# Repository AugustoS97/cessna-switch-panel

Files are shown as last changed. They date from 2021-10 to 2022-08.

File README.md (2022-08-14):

# cessna-switch-panel

## Descripción

Panel para interruptores de luces y magnetos para Cessna 172 y otros simuladores de vuelo. Diseñado para ser compatible con MobiFlight y FSX, MSFS2020, Xplane y Prepar3D.

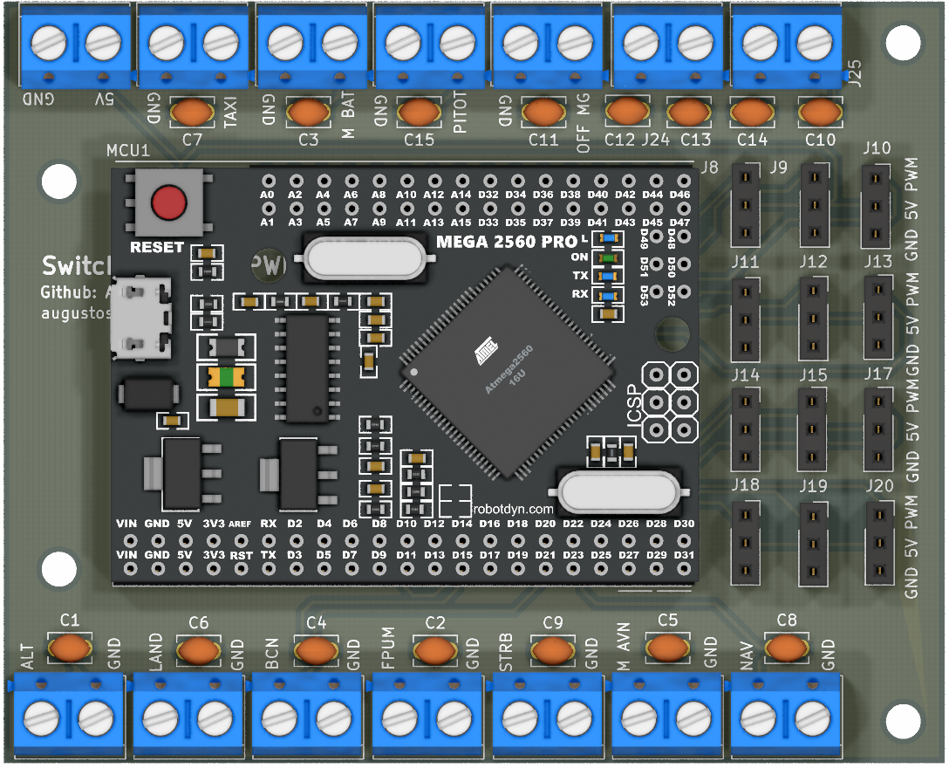
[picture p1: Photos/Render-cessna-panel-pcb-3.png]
PCB Top


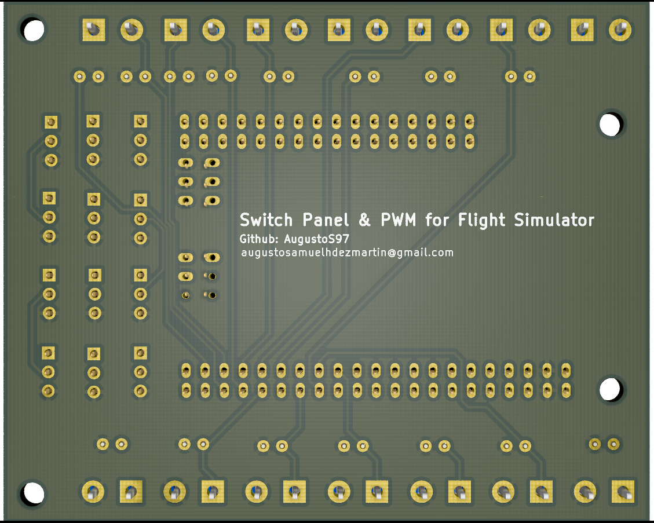
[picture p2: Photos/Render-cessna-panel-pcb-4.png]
PCB Bottom


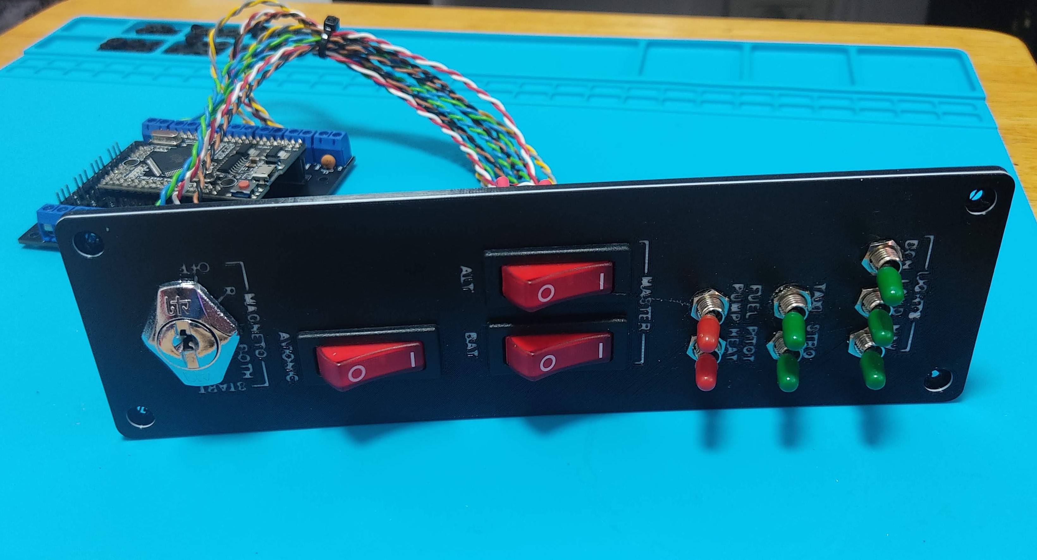
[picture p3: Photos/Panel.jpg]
Panel


## Contenido del proyecto

- En la carpeta cessna-panel-pcb se incluye el diseño de PCB para ser controlado con un arduino Mega 2560 Pro, con los ficheros GERBER para ser pedido en JLCPCB.
- En la carpeta Frame-design se localizan los diseños 3D de los marcos para los interruptores tanto para instalación vertical como horizontal.
- En la carpeta PCB-Support se localizan los diseños 3D de la carcasa para la electrónica.
- En la carpeta Mobiflight Confif se localiza el fichero de configuración d eMobiflight para Cessna 172 y MSFS2020.

Enlace del diseño de [paneles](https://www.thingiverse.com/thing:5461243) y [carcasa](https://www.thingiverse.com/thing:5461228) en Thingiverse.

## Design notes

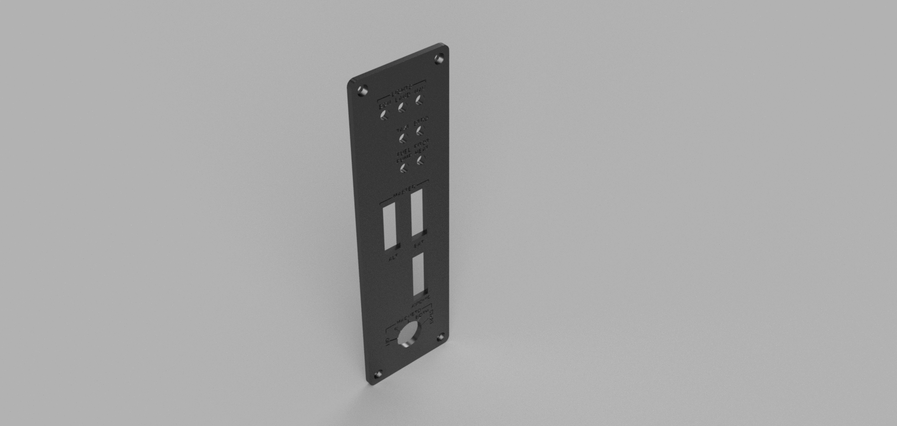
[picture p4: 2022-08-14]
Frame-design/Vertical version/IMAGES/Frame-design-switches-vertical.png

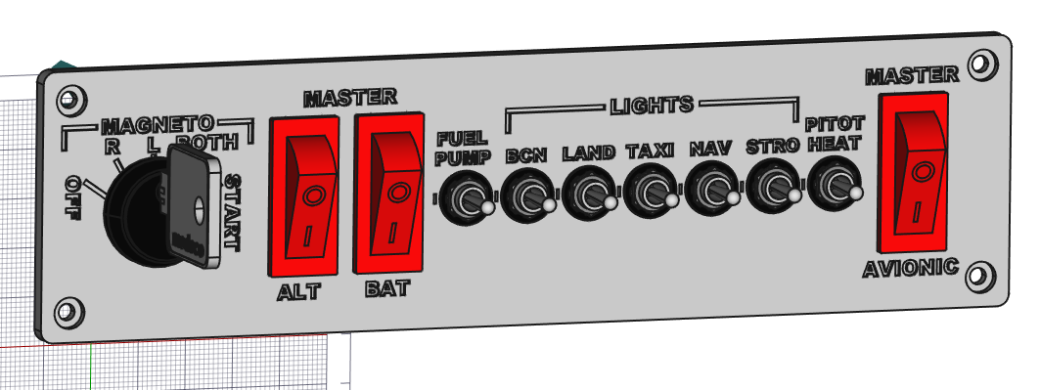
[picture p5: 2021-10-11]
Frame-design/Horizontal version/IMAGES/Frame-design-switches-vertical_2.png

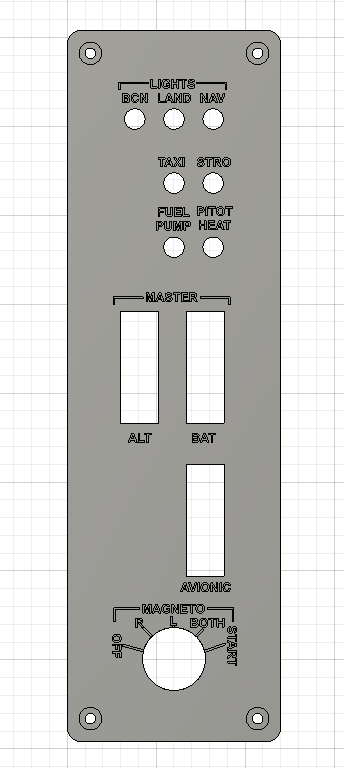
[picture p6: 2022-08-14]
Frame-design/Vertical version/IMAGES/Frame-design-switches-vertical_2.png

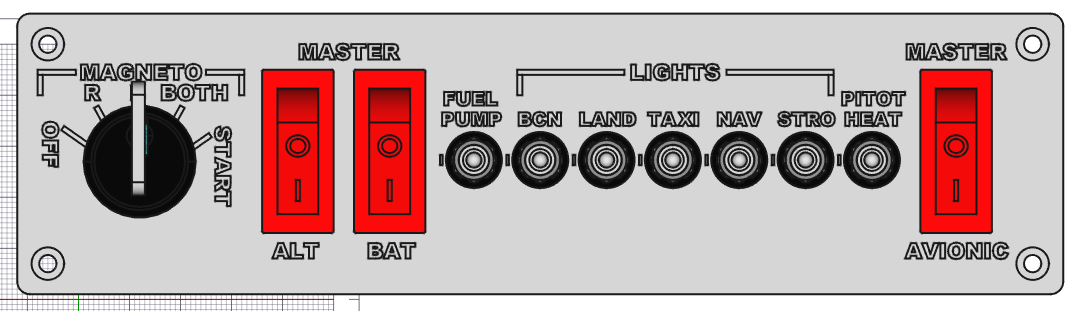
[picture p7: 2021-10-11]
Frame-design/Horizontal version/IMAGES/Frame-design-switches-vertical_0.png

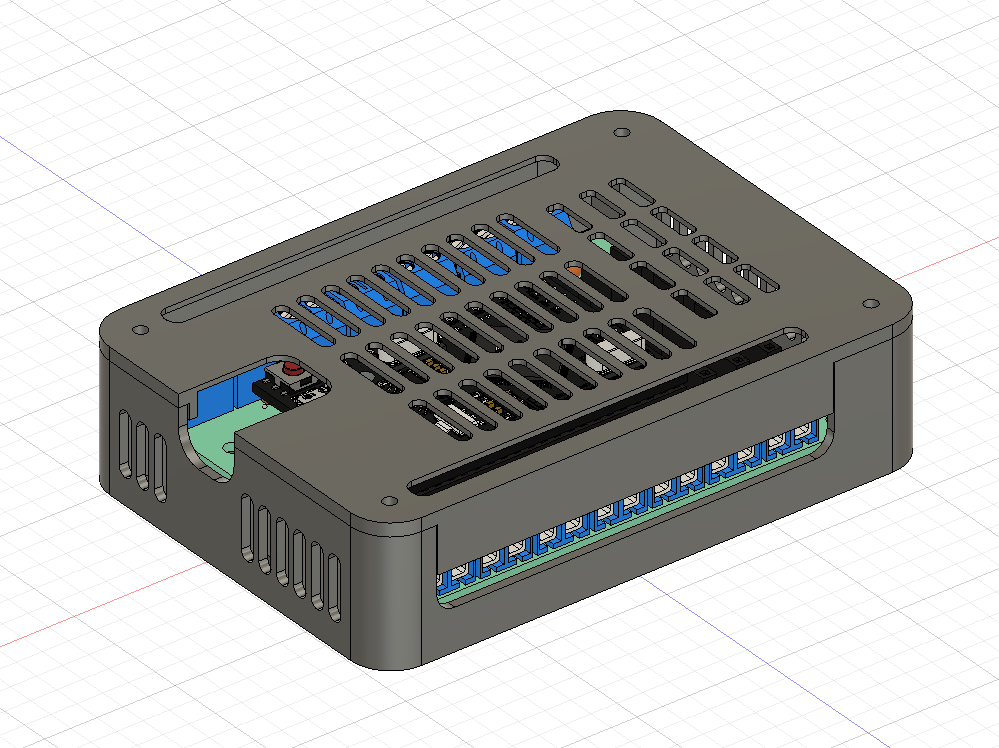
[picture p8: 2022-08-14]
PCB-Support/IMAGES/Diseño de soporte.png

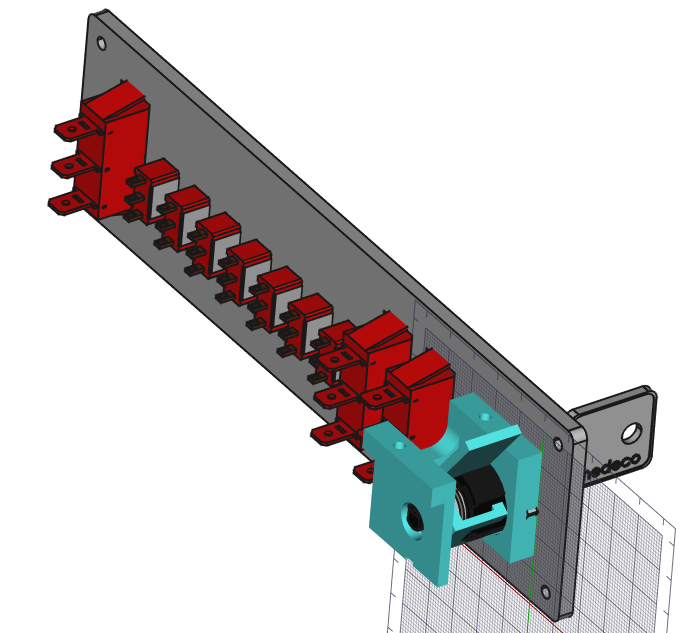
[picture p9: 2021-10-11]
Frame-design/Horizontal version/IMAGES/Frame-design-switches-vertical_1.png

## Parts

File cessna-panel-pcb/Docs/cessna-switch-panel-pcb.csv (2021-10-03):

Ref | Qnty | Value | Cmp name | Footprint | Description | Vendor
C1, C2, C3, C4, C5, C6, C7, C8, C9, C10, C11, C12, C13, C14, C15, | 15 | 10nF | C_Small | Capacitor_THT:C_Disc_D3.8mm_W2.6mm_P2.50mm | Unpolarized capacitor, small symbol
J1, J2, J3, J4, J5, J6, J7, J16, J21, J22, J23, J24, J25, J26, | 14 | Screw_Terminal_01x02 | Screw_Terminal_01x02 | TerminalBlock:TerminalBlock_bornier-2_P5.08mm | Generic screw terminal, single row, 01x02, script generated (kicad-library-utils/schlib/autogen/connector/)
J8, | 1 | PWM1_CONN | Conn_01x03 | Connector_PinSocket_2.54mm:PinSocket_1x03_P2.54mm_Vertical | Generic connector, single row, 01x03, script generated (kicad-library-utils/schlib/autogen/connector/)
J9, | 1 | PWM2_CONN | Conn_01x03 | Connector_PinSocket_2.54mm:PinSocket_1x03_P2.54mm_Vertical | Generic connector, single row, 01x03, script generated (kicad-library-utils/schlib/autogen/connector/)
J10, | 1 | PWM3_CONN | Conn_01x03 | Connector_PinSocket_2.54mm:PinSocket_1x03_P2.54mm_Vertical | Generic connector, single row, 01x03, script generated (kicad-library-utils/schlib/autogen/connector/)
J11, | 1 | PWM4_CONN | Conn_01x03 | Connector_PinSocket_2.54mm:PinSocket_1x03_P2.54mm_Vertical | Generic connector, single row, 01x03, script generated (kicad-library-utils/schlib/autogen/connector/)
J12, | 1 | PWM5_CONN | Conn_01x03 | Connector_PinSocket_2.54mm:PinSocket_1x03_P2.54mm_Vertical | Generic connector, single row, 01x03, script generated (kicad-library-utils/schlib/autogen/connector/)
J13, | 1 | PWM6_CONN | Conn_01x03 | Connector_PinSocket_2.54mm:PinSocket_1x03_P2.54mm_Vertical | Generic connector, single row, 01x03, script generated (kicad-library-utils/schlib/autogen/connector/)
J14, | 1 | PWM7_CONN | Conn_01x03 | Connector_PinSocket_2.54mm:PinSocket_1x03_P2.54mm_Vertical | Generic connector, single row, 01x03, script generated (kicad-library-utils/schlib/autogen/connector/)
J15, | 1 | PWM8_CONN | Conn_01x03 | Connector_PinSocket_2.54mm:PinSocket_1x03_P2.54mm_Vertical | Generic connector, single row, 01x03, script generated (kicad-library-utils/schlib/autogen/connector/)
J17, | 1 | PWM9_CONN | Conn_01x03 | Connector_PinSocket_2.54mm:PinSocket_1x03_P2.54mm_Vertical | Generic connector, single row, 01x03, script generated (kicad-library-utils/schlib/autogen/connector/)
J18, | 1 | PWM10_CONN | Conn_01x03 | Connector_PinSocket_2.54mm:PinSocket_1x03_P2.54mm_Vertical | Generic connector, single row, 01x03, script generated (kicad-library-utils/schlib/autogen/connector/)
J19, | 1 | PWM11_CONN | Conn_01x03 | Connector_PinSocket_2.54mm:PinSocket_1x03_P2.54mm_Vertical | Generic connector, single row, 01x03, script generated (kicad-library-utils/schlib/autogen/connector/)
J20, | 1 | PWM12_CONN | Conn_01x03 | Connector_PinSocket_2.54mm:PinSocket_1x03_P2.54mm_Vertical | Generic connector, single row, 01x03, script generated (kicad-library-utils/schlib/autogen/connector/)
MCU1, | 1 | Master_Arduino_Mega_Embebido_Arduino_Mega_v3 | Master_Arduino_Mega_Embebido_Arduino_Mega_v3 | Mega2560-pro-mini-radio:MEGA_Embebido

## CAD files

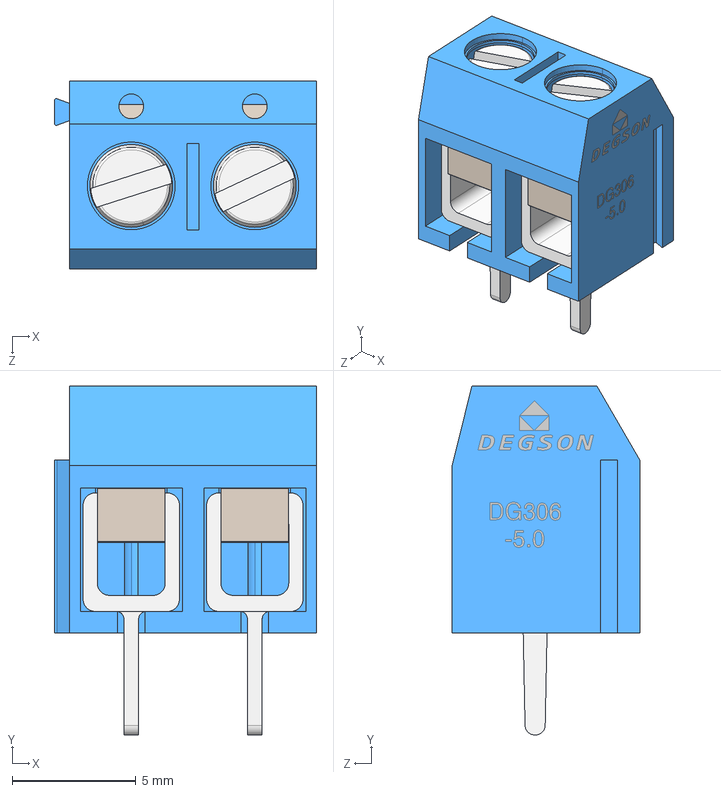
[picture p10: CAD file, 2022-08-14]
cessna-panel-pcb/3D Model/DG306-5.STEP
10.6 x 14.1 x 7.60 mm
Case
Screw x 2
Terminal x 2
Spring x 2

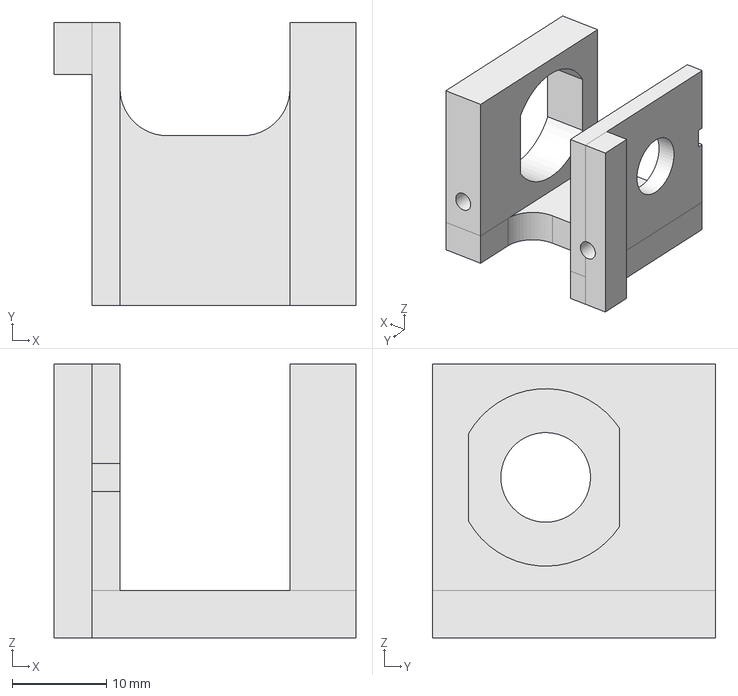
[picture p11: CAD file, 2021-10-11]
Frame-design/Horizontal version/AXUILIAR DESIGN/key-switch/key_switch.FCStd
32.0 x 30.0 x 29.0 mm

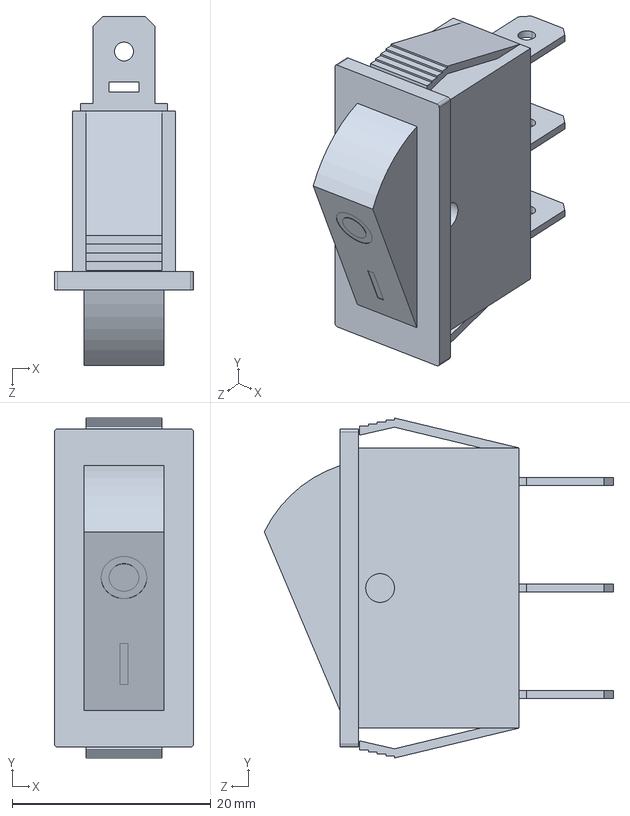
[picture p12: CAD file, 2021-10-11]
Frame-design/Horizontal version/AXUILIAR DESIGN/Single Pole Rocker Switch.STEP
14.0 x 34.2 x 35.1 mm

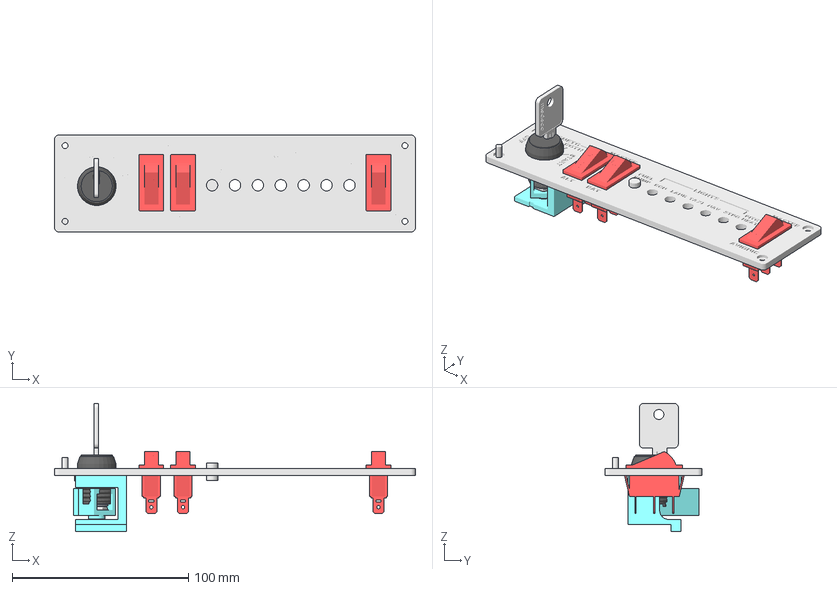
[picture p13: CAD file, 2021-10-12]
Frame-design/Horizontal version/Frame.FCStd
205.0 x 55.0 x 72.9 mm
Cilindro
Cilindro001
Panel_grabado_switches_bordes_red
Outer-Medeco-Lock
Inner-Medeco-Lock
Washer-4-Lock-Latch
Nut-4-Lock-Latch
Nut-4-Medeco-Lock
Key-4-Medeco-Lock
Single Pole Rocker Switch002
Single Pole Rocker Switch001
Single Pole Rocker Switch
key_switch
Redesigned_Spring_Back_Handle

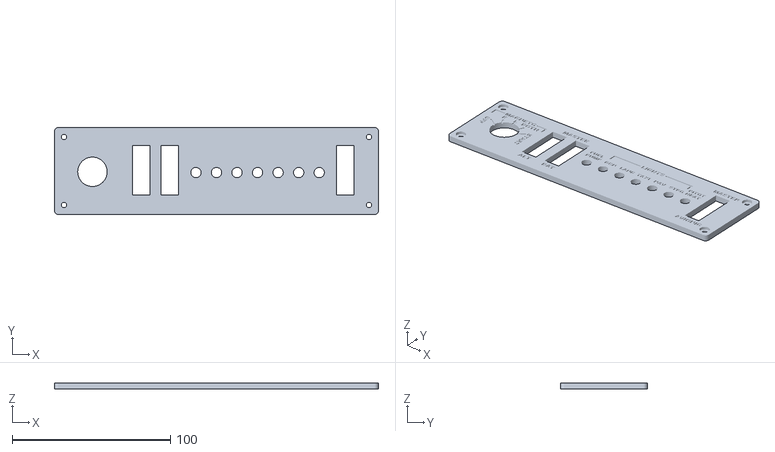
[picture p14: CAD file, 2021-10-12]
Frame-design/Horizontal version/STL/Frame-design-switches-horizontal.stl
205.0 x 55.0 x 4.00

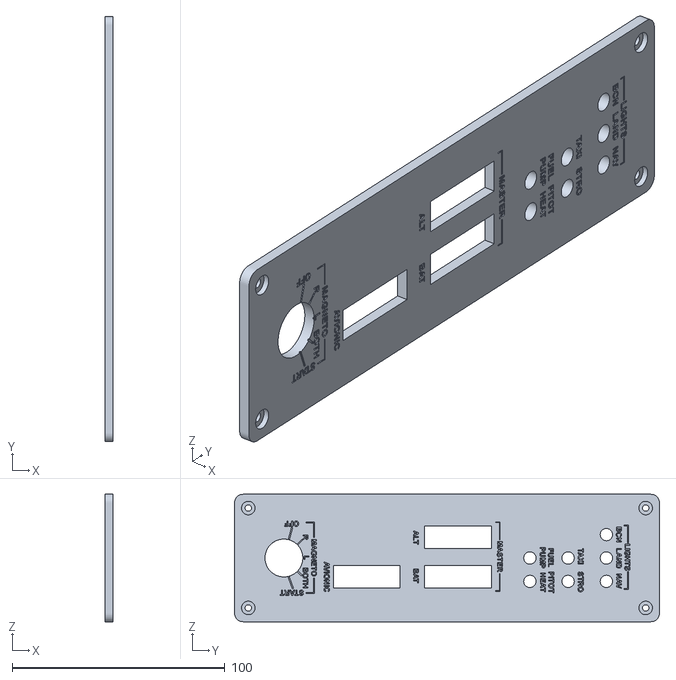
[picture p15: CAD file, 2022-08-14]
Frame-design/Vertical version/STL/Frame-design-switches-vertical.stl
3.60 x 200.0 x 60.0

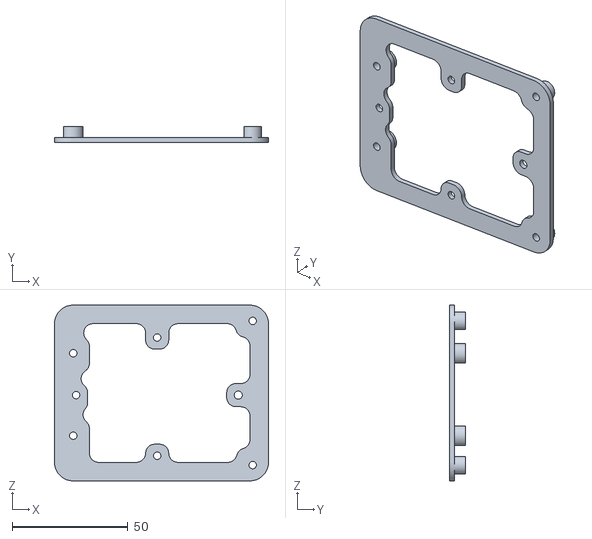
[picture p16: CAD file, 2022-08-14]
PCB-Support/STL/Soprte-PCB-Switch.stl
92.4 x 6.80 x 75.9

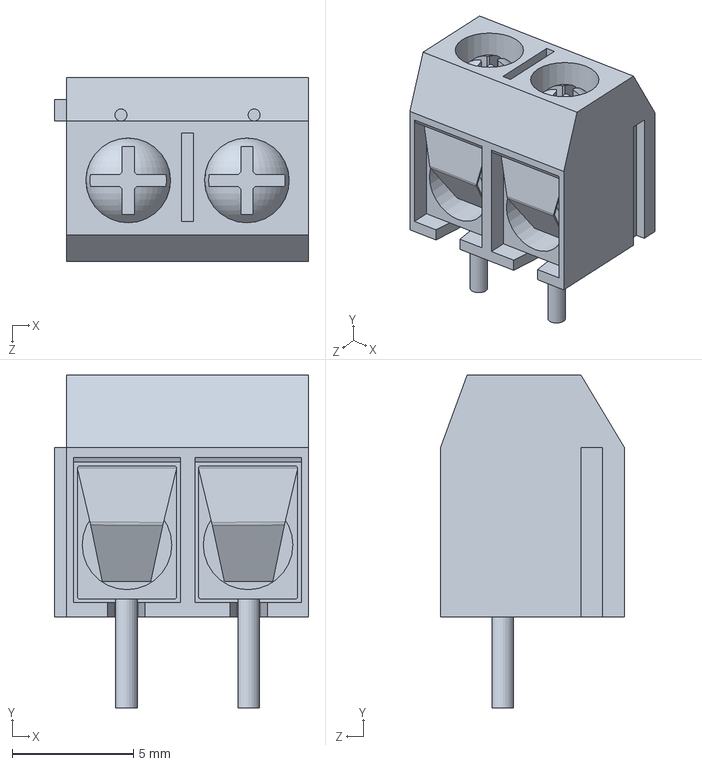
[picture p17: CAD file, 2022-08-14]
cessna-panel-pcb/3D Model/bornera.SLDPRT
10.5 x 13.8 x 7.60 mm

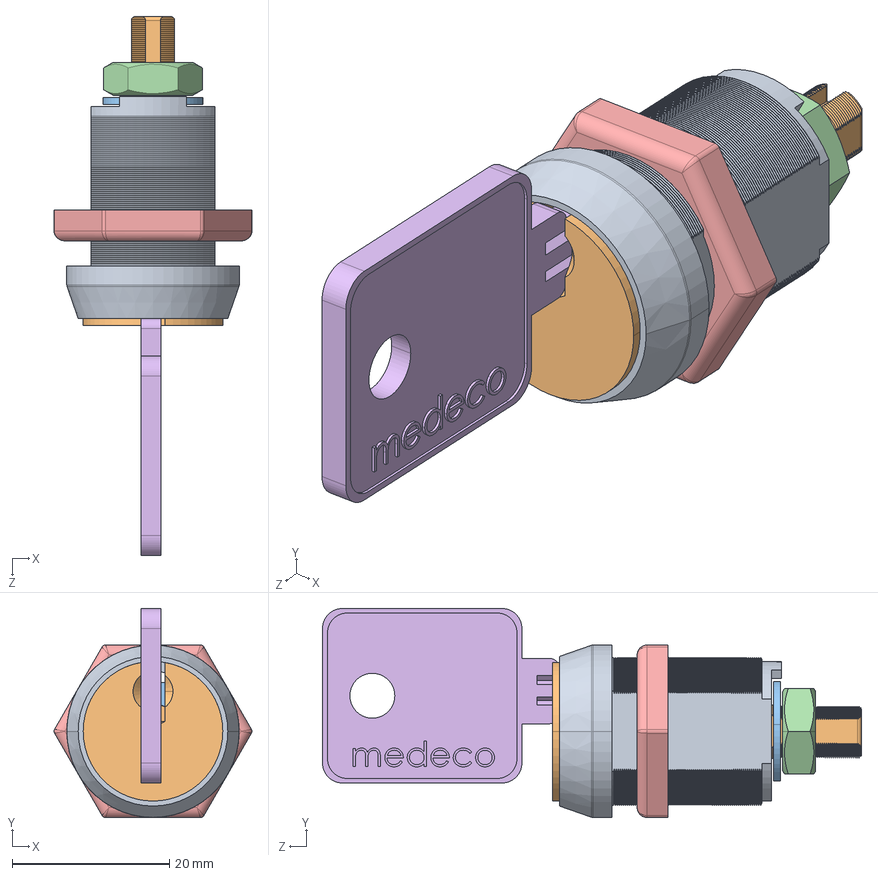
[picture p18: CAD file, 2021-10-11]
Frame-design/Horizontal version/AXUILIAR DESIGN/key-switch/STEP LOCK_and_KEY.STEP
25.2 x 26.6 x 68.6 mm
Outer-Medeco-Lock
Inner-Medeco-Lock
Washer-4-Lock-Latch
Nut-4-Lock-Latch
Nut-4-Medeco-Lock
Key-4-Medeco-Lock

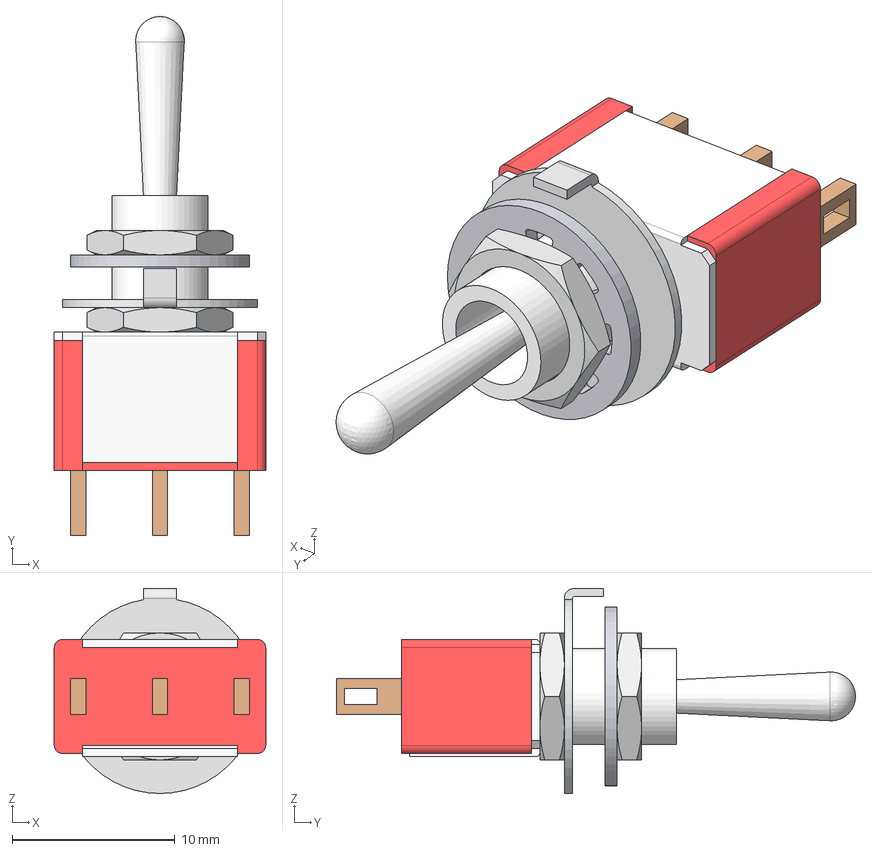
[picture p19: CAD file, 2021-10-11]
Frame-design/Horizontal version/AXUILIAR DESIGN/SPDT Toggle Switch.stp
13.0 x 31.9 x 12.6 mm
SPDT Toggle Switch Base
SPDT Toggle Switch Pin x 3
SPDT Toggle Switch Treaded Tube
Toggle Switch
M6x0.5 Hex Nut x 2
SPDT Toggle Switch Anti-Rotation Washer
AS 1969 (Internal Tooth Lock Washer Type A) M6

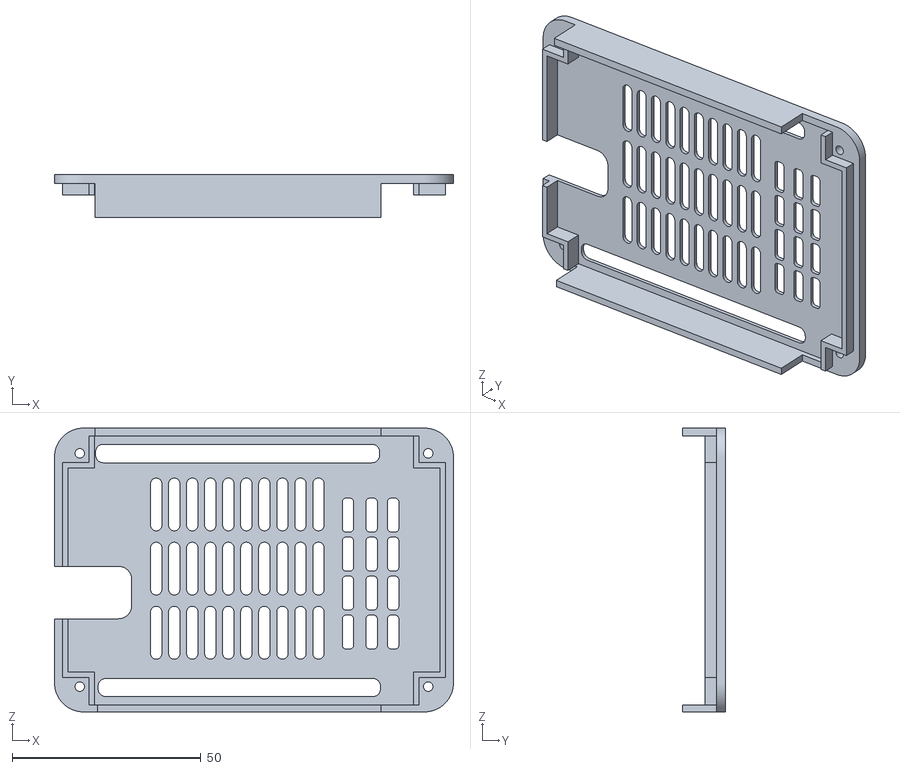
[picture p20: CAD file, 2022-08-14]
PCB-Support/STL/Caja-PCB-Switch-Tapa.stl
105.8 x 11.5 x 75.2

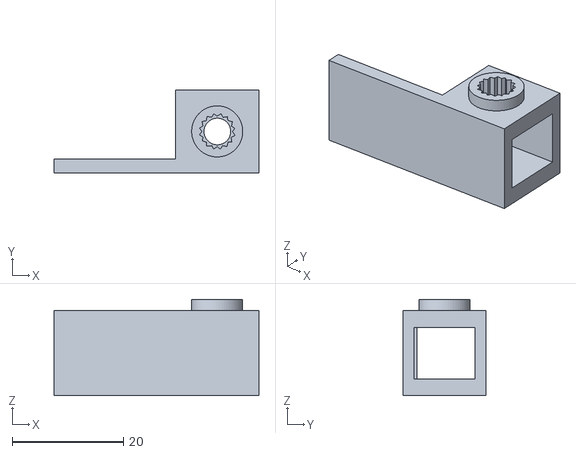
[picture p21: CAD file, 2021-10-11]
Frame-design/Horizontal version/AXUILIAR DESIGN/key-switch/Redesigned_Spring_Back_Handle.stl
36.9 x 15.0 x 17.3

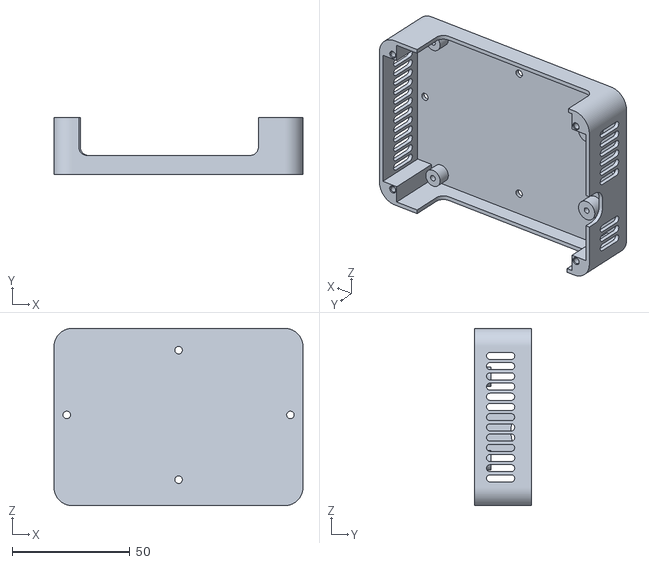
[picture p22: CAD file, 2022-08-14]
PCB-Support/STL/Caja-PCB-Switch-Inf.stl
105.8 x 24.0 x 75.2

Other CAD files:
Frame-design/Horizontal version/AXUILIAR DESIGN/key-switch/key_switch.stl
Frame-design/Vertical version/Fusion 360/Estructura v25.f3d

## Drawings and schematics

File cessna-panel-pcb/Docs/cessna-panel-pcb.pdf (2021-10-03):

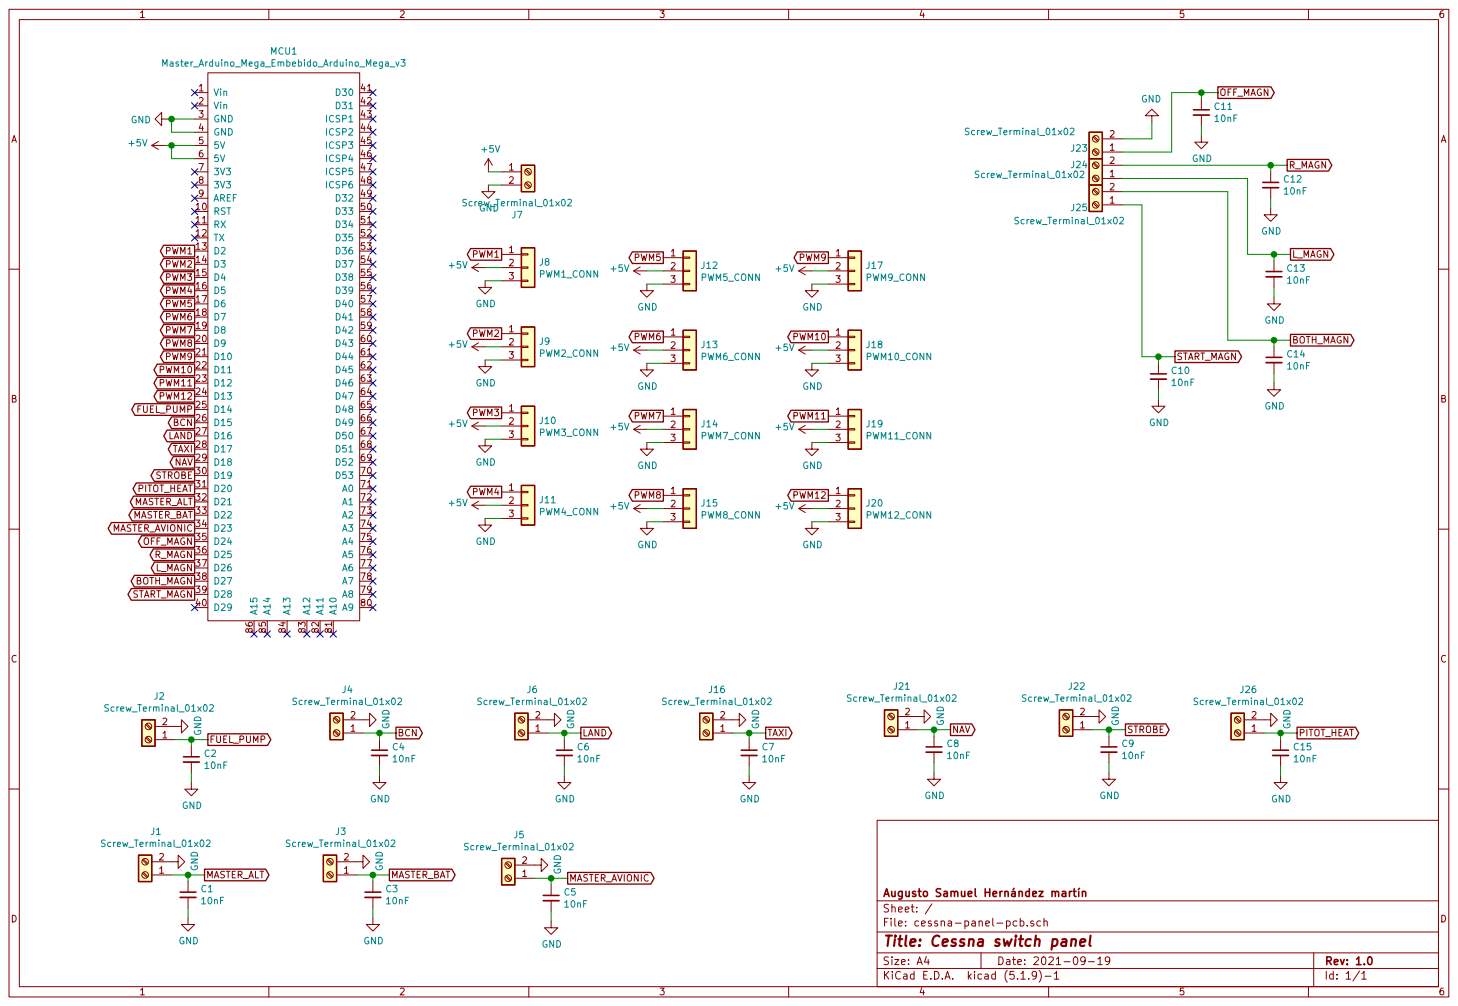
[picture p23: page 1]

File: cessna-panel-pcb.sch Sheet: / Augusto Samuel Hernández martín GND

Id: 1/1 Title: Cessna switch panel

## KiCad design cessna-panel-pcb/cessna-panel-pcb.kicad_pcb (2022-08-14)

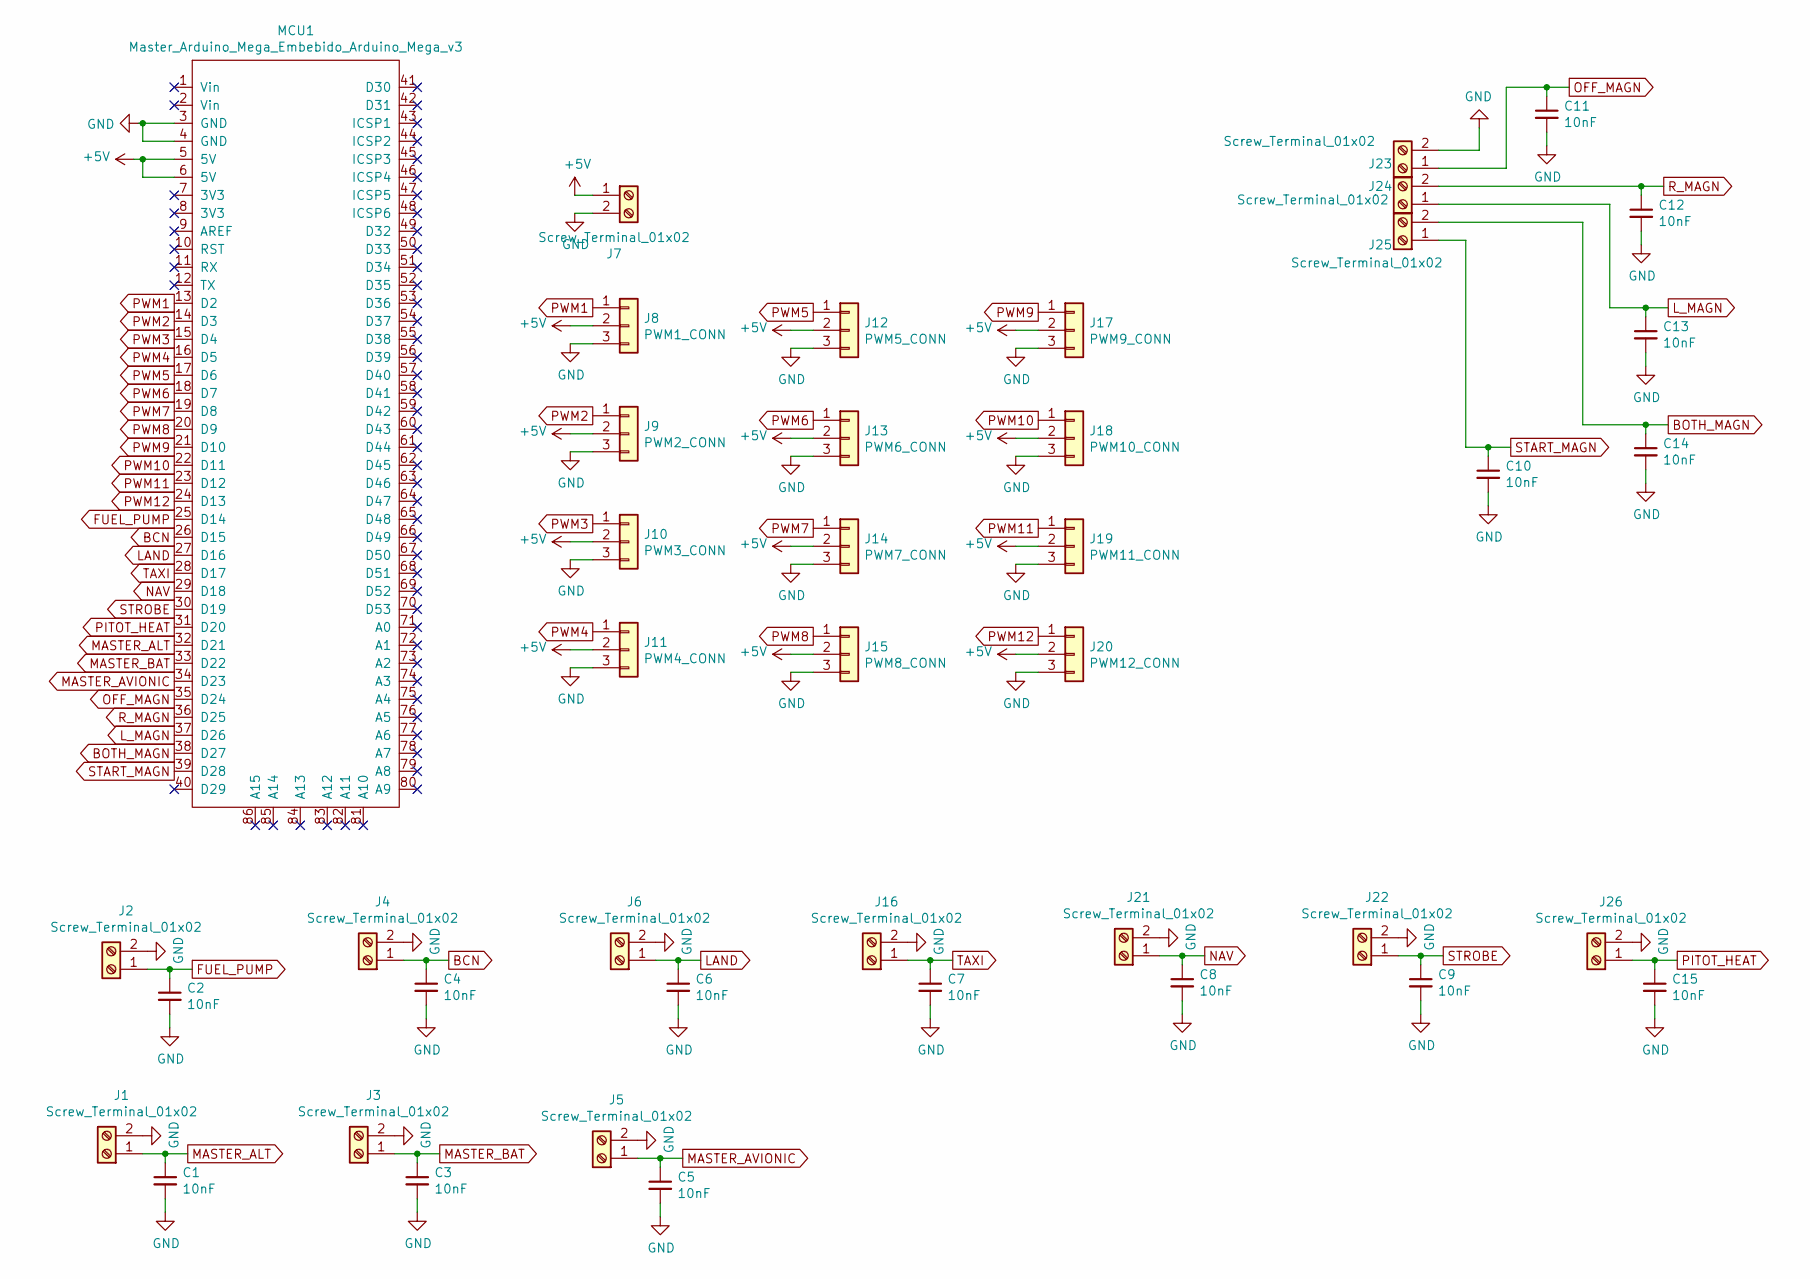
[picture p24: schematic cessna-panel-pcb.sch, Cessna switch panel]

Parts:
C1, C2, C3, C4, C5, C6, C7, C8, C9, C10, C11, C12, C13, C14, C15: 10nF; C_Disc_D3.8mm_W2.6mm_P2.50mm
J1, J2, J3, J4, J5, J6, J7, J16, J21, J22, J23, J24, J25, J26: Screw_Terminal_01x02; TerminalBlock_bornier-2_P5.08mm
J8: PWM1_CONN; PinSocket_1x03_P2.54mm_Vertical
J9: PWM2_CONN; PinSocket_1x03_P2.54mm_Vertical
J10: PWM3_CONN; PinSocket_1x03_P2.54mm_Vertical
J11: PWM4_CONN; PinSocket_1x03_P2.54mm_Vertical
J12: PWM5_CONN; PinSocket_1x03_P2.54mm_Vertical
J13: PWM6_CONN; PinSocket_1x03_P2.54mm_Vertical
J14: PWM7_CONN; PinSocket_1x03_P2.54mm_Vertical
J15: PWM8_CONN; PinSocket_1x03_P2.54mm_Vertical
J17: PWM9_CONN; PinSocket_1x03_P2.54mm_Vertical
J18: PWM10_CONN; PinSocket_1x03_P2.54mm_Vertical
J19: PWM11_CONN; PinSocket_1x03_P2.54mm_Vertical
J20: PWM12_CONN; PinSocket_1x03_P2.54mm_Vertical
MCU1: Master_Arduino_Mega_Embebido_Arduino_Mega_v3; MEGA_Embebido

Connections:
+5V: J7.1, J8.2, J9.2, J10.2, J11.2, J12.2, J13.2, J14.2, J15.2, J17.2, J18.2, J19.2, J20.2, MCU1.5 (5V), MCU1.6 (5V)
BCN: C4.1, J4.1, MCU1.26 (D15)
BOTH_MAGN: C14.1, J25.2, MCU1.38 (D27)
FUEL_PUMP: C2.1, J2.1, MCU1.25 (D14)
GND: C1.2, C2.2, C3.2, C4.2, C5.2, C6.2, C7.2, C8.2, C9.2, C10.2, C11.2, C12.2, C13.2, C14.2, C15.2, J1.2, J2.2, J3.2, J4.2, J5.2, J6.2, J7.2, J8.3, J9.3, J10.3, J11.3, J12.3, J13.3, J14.3, J15.3, J16.2, J17.3, J18.3, J19.3, J20.3, J21.2, J22.2, J23.2, J26.2, MCU1.3 (GND), MCU1.4 (GND)
LAND: C6.1, J6.1, MCU1.27 (D16)
L_MAGN: C13.1, J24.1, MCU1.37 (D26)
MASTER_ALT: C1.1, J1.1, MCU1.32 (D21)
MASTER_AVIONIC: C5.1, J5.1, MCU1.34 (D23)
MASTER_BAT: C3.1, J3.1, MCU1.33 (D22)
NAV: C8.1, J21.1, MCU1.29 (D18)
OFF_MAGN: C11.1, J23.1, MCU1.35 (D24)
PITOT_HEAT: C15.1, J26.1, MCU1.31 (D20)
PWM1: J8.1, MCU1.13 (D2)
PWM2: J9.1, MCU1.14 (D3)
PWM3: J10.1, MCU1.15 (D4)
PWM4: J11.1, MCU1.16 (D5)
PWM5: J12.1, MCU1.17 (D6)
PWM6: J13.1, MCU1.18 (D7)
PWM7: J14.1, MCU1.19 (D8)
PWM8: J15.1, MCU1.20 (D9)
PWM9: J17.1, MCU1.21 (D10)
PWM10: J18.1, MCU1.22 (D11)
PWM11: J19.1, MCU1.23 (D12)
PWM12: J20.1, MCU1.24 (D13)
R_MAGN: C12.1, J24.2, MCU1.36 (D25)
START_MAGN: C10.1, J25.1, MCU1.39 (D28)
STROBE: C9.1, J22.1, MCU1.30 (D19)
TAXI: C7.1, J16.1, MCU1.28 (D17)

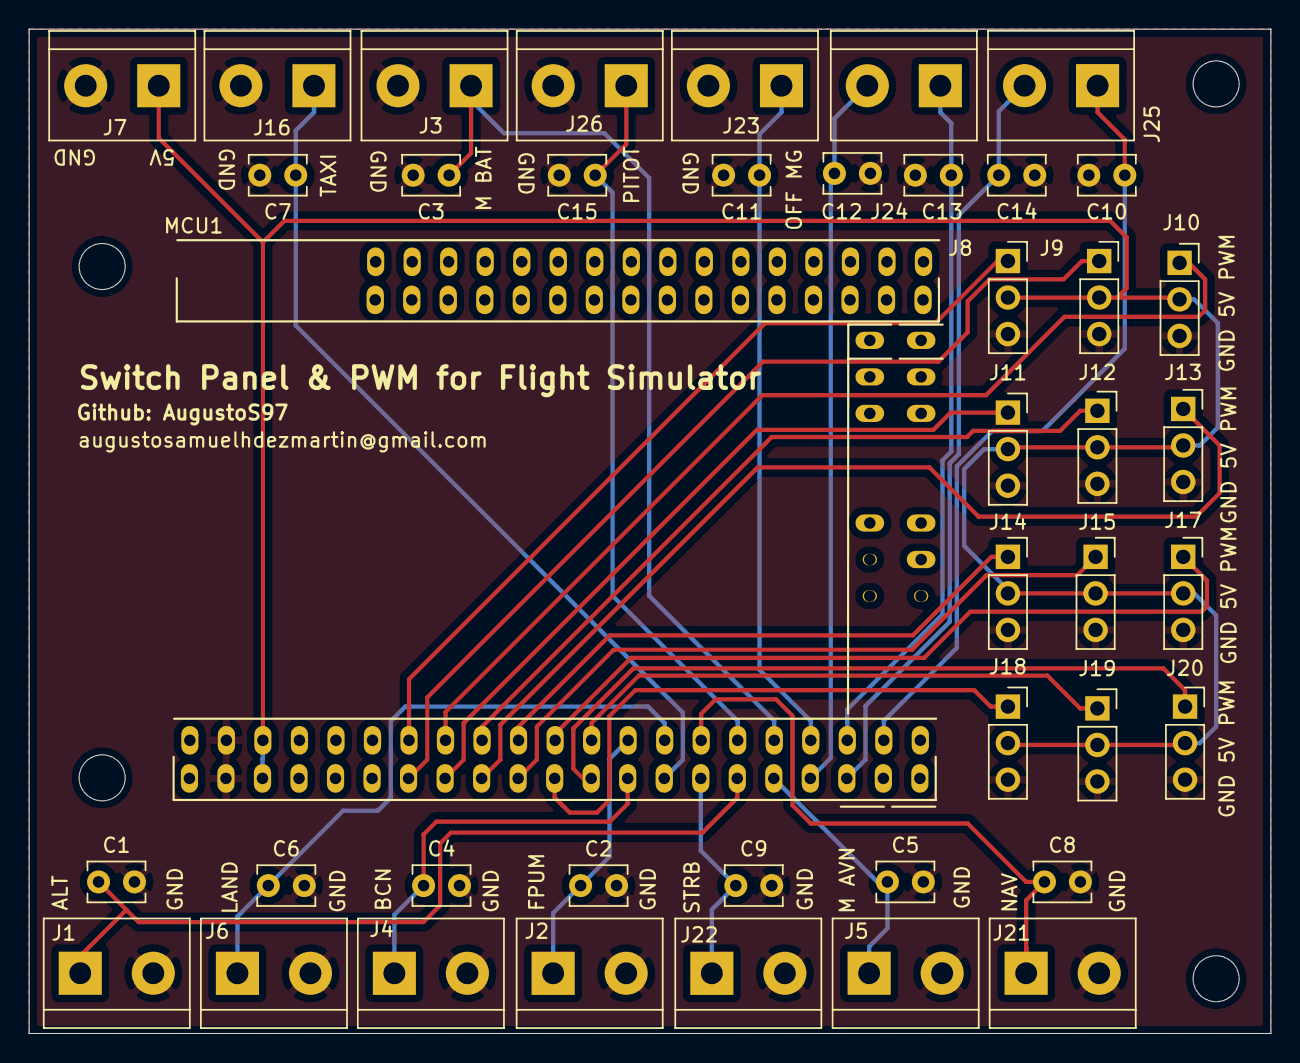
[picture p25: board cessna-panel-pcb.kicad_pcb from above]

Board: 2 copper layers, 86.4 x 69.9 mm, 46 parts (0 on the bottom side), 29 nets.

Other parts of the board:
H1, H2, H3, H4: MountingHole_3.2mm_M3

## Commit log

2021-09-19 Añadido el esquematico. Falta la PCB.
    [cessna-panel-pcb.kicad_pcb, cessna-panel-pcb.sch]
2021-10-03 Diseño de PCb para conectar los Switches y los servos diseñada.
    [cessna-panel-pcb-B_Cu.gbr, cessna-panel-pcb-B_Mask.gbr, cessna-panel-pcb-B_Paste.gbr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]
2021-10-10 Modificados los GERBERs
2021-10-11 Añadido el diseño del panel y sus ficheros imprimibles.
    [Frame.FCStd, Panel_Grabado_Switches.stl, Redesigned_Spring_Back_Handle.stl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]
2021-10-12 Corregidas las dimensiones de los rocket switch
    [Frame.FCStd, Panel_Grabado_Switches.stl]
2022-08-14 Añadidos los diseños de carcasas, el modelo 3D de PCB y los ficheros Fusion 360
    [Caja-PCB-Switch-Inf.stl, Caja-PCB-Switch-Tapa.stl, DG306-5.STEP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]
